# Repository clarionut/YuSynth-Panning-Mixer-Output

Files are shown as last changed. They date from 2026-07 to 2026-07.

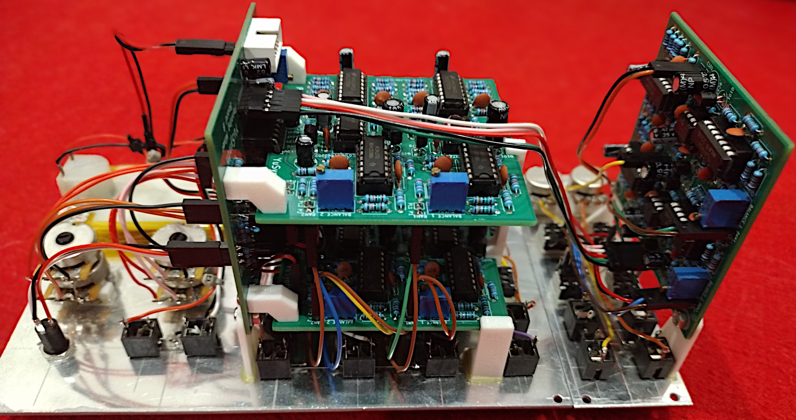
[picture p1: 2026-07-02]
Pictures/PanMixOut1.jpg

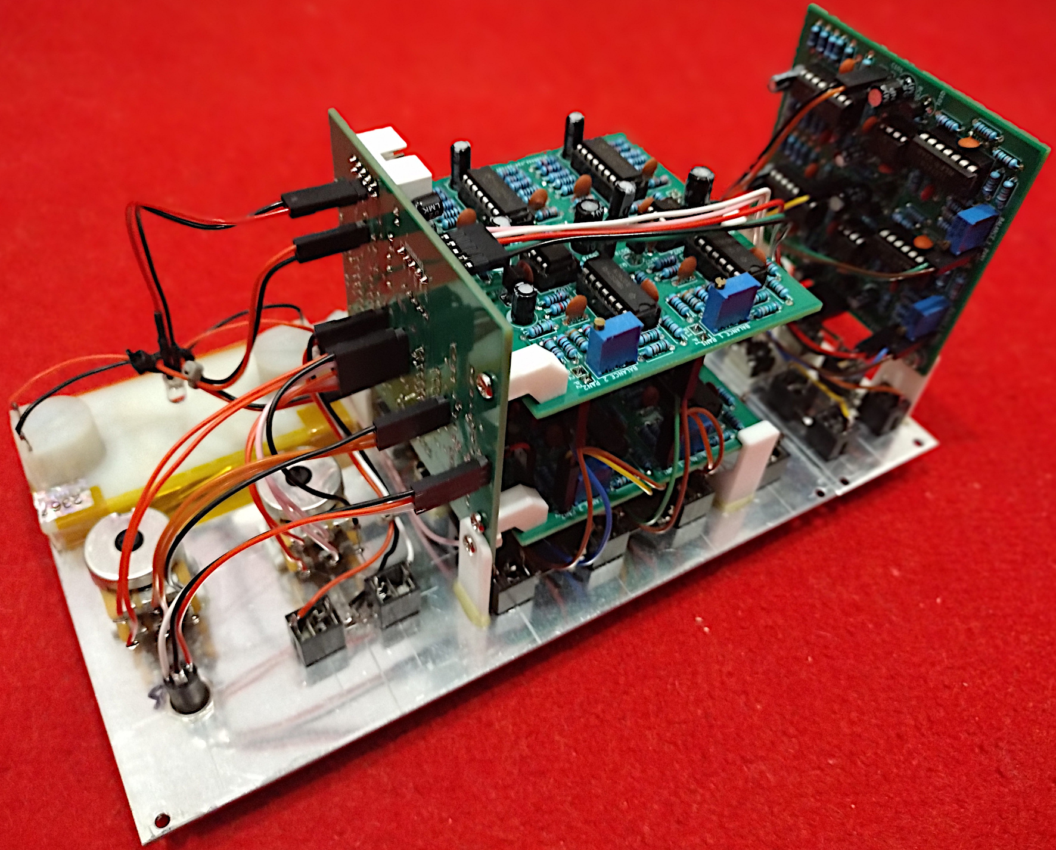
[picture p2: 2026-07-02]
Pictures/PanMixOut2.jpg

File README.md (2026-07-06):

# YuSynth Panning Mixer/Output
An extensible version of the YuSynth Output mixer &amp; VC-panner, minus the tone control circuitry.



Very early in the construction of my modular synth it became obvious that I was going to need a multi-channel mixer as an output stage. I'd already built a few YuSynth modules, so his [Mixout-VC Panner](https://yusynth.net/Modular/EN/MIXOUT/index.html) seemed like a promising choice especially as I had an old dual VU meter which could be pressed into service.

The original design includes a passive tone control circuit (which I chose to omit) and uses a two-board architecture with the four VC panner circuits on one board and the mixer and output circuitry on another. My synth is in Eurorack format, so I wanted to keep the board sizes as small as possible (which also makes them cheaper!). I decided to use an alternative physical architecture with the mixer output board (board B in my design) as a motherboard, with two 2-channel VC-panner boards (board A) plugged into it using pin headers.

This allows easy extensibility by adding further 2-channel VC-panner boards mounted on their own panels, daisy-chained from a header on the motherboard. I have indeed added an additional pair of inputs since originally building the module. Details of the construction are shown in the [pictures](https://github.com/clarionut/YuSynth-Panning-Mixer-Output/tree/main/Pictures) folder. Note that the two VC-panner boards mounted on the motherboard have the header pins on the front side on one board and the back side on the other to keep the wiring as clean as possible. Most of the pin headers on the motherboard are on the back side of the board. The pictures also show the additional input board and panel.

I replaced the original non-backlit VU meter with one which can be illuminated, and soldered a 2 pin header to the back of the main power input connection with flying leads to the resistor/LED positioned behind the meter.

The [schematic](https://github.com/clarionut/YuSynth-Panning-Mixer-Output/tree/main/Schematic) folder contains PDFs of the schematic and layout for the VC-panner boards (A) and the motherboard (B). The Kicad projects for these are in their own individual subfolders.

I've also include the [gerbers](https://github.com/clarionut/YuSynth-Panning-Mixer-Output/tree/main/Gerbers) in case these are of direct use to anyone.

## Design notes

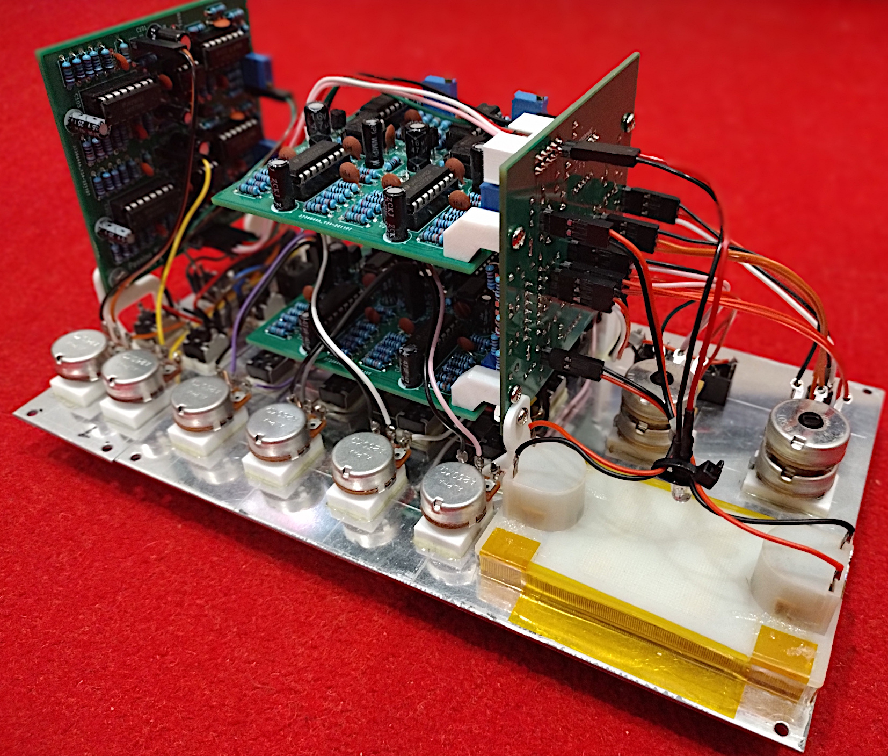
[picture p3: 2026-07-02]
Pictures/PanMixOut3.jpg

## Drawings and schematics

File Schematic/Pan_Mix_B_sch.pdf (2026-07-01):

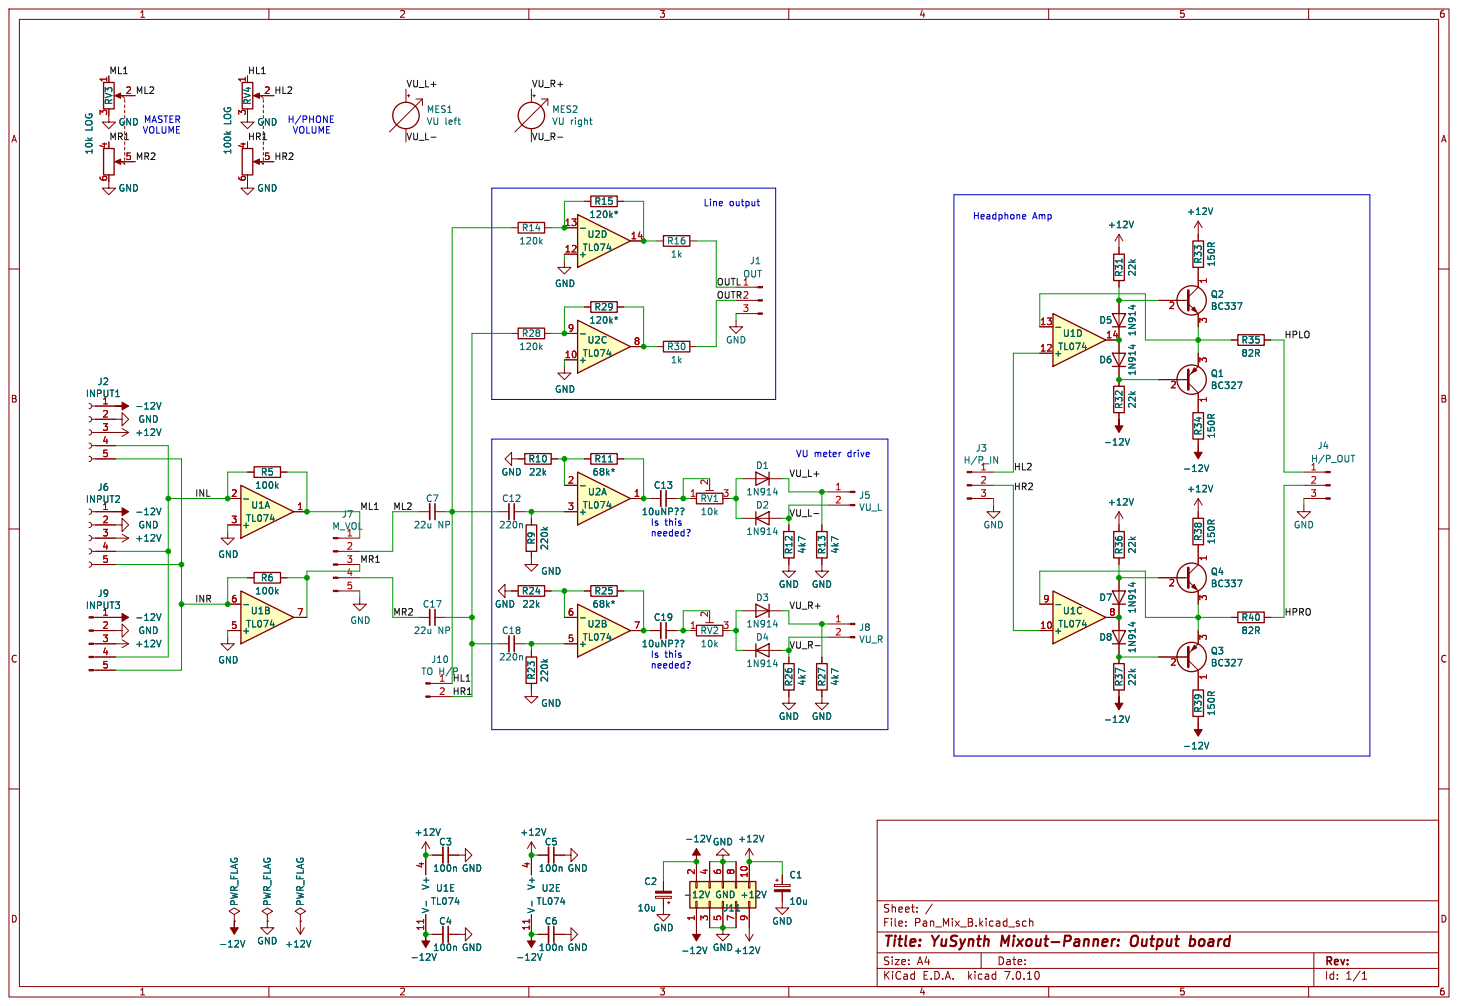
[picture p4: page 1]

10k MES2 VU right MES1 VU left +
1k GND

6 GND GND GND RV3 10k LOG

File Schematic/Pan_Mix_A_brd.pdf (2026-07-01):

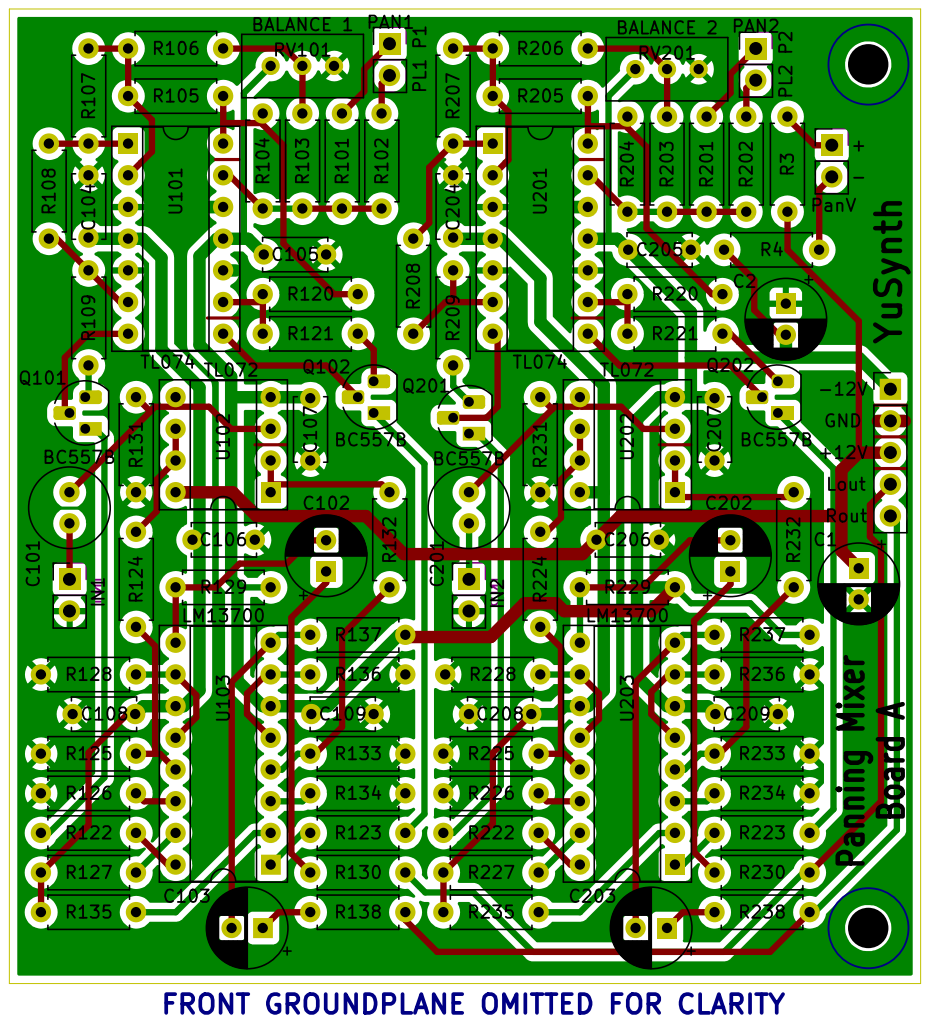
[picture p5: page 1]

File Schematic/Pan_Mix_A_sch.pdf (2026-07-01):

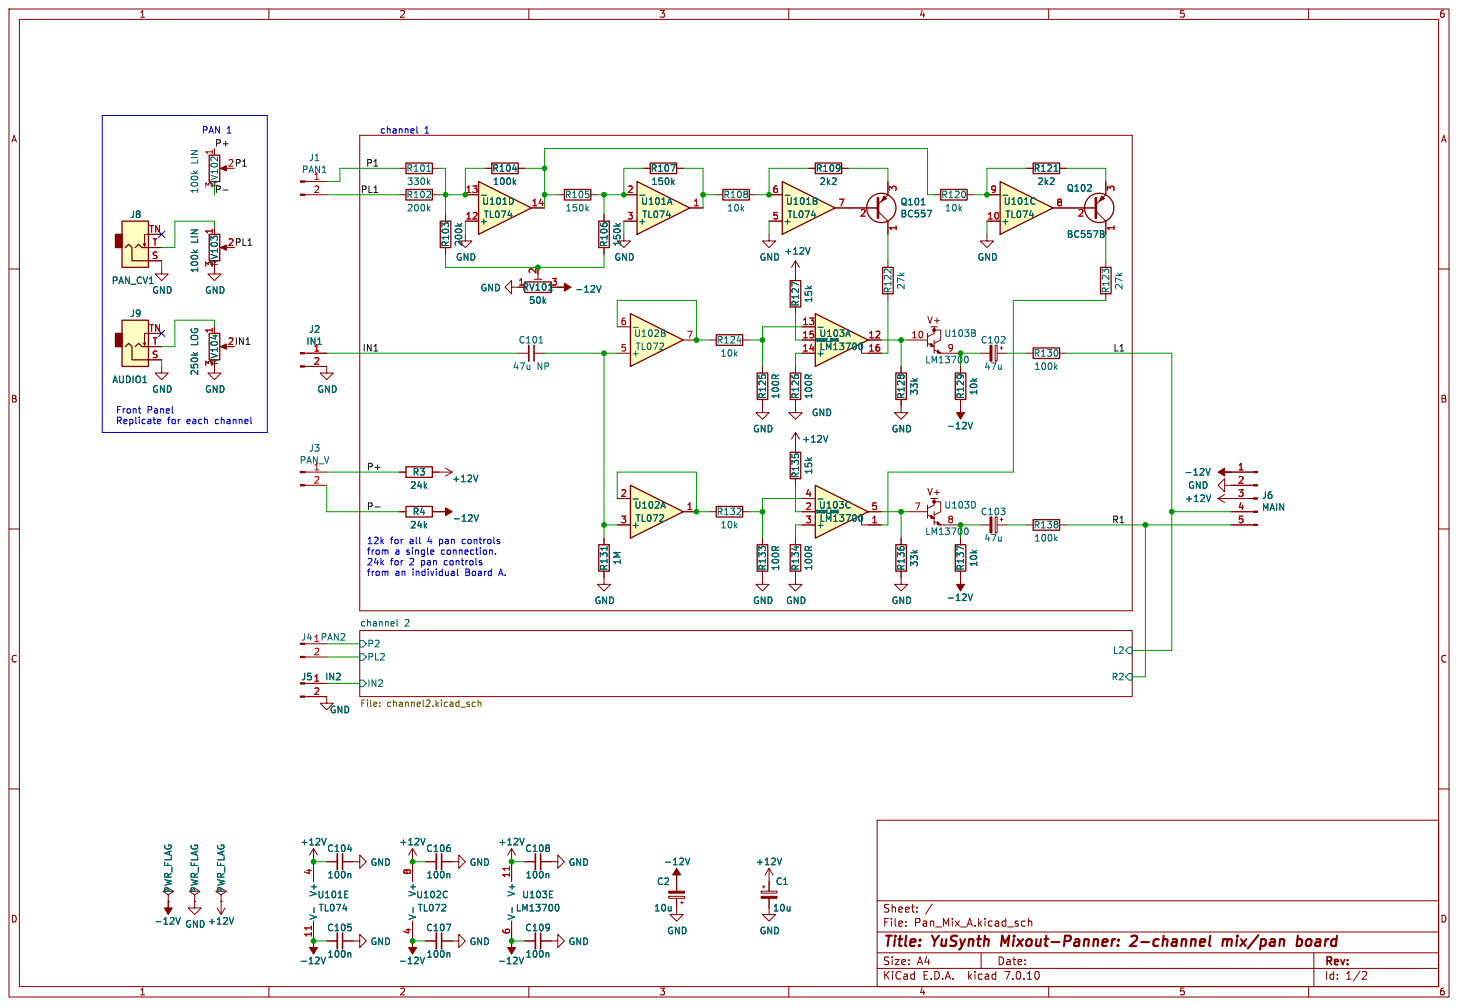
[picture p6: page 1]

12k for all 4 pan controls
from a single connection. 24k for 2 pan controls

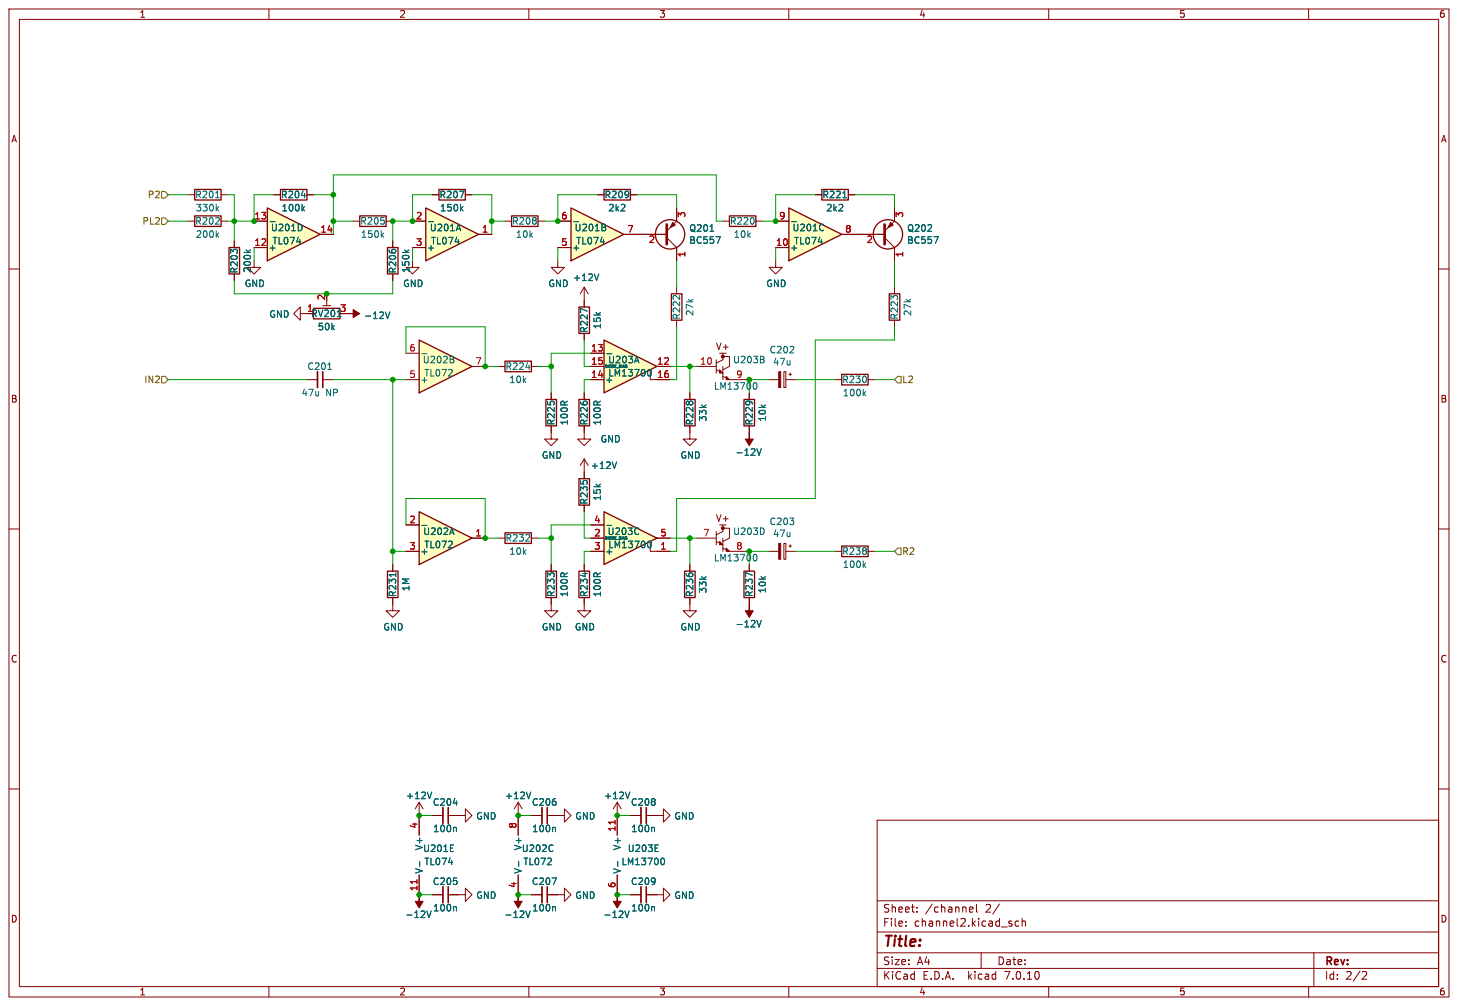
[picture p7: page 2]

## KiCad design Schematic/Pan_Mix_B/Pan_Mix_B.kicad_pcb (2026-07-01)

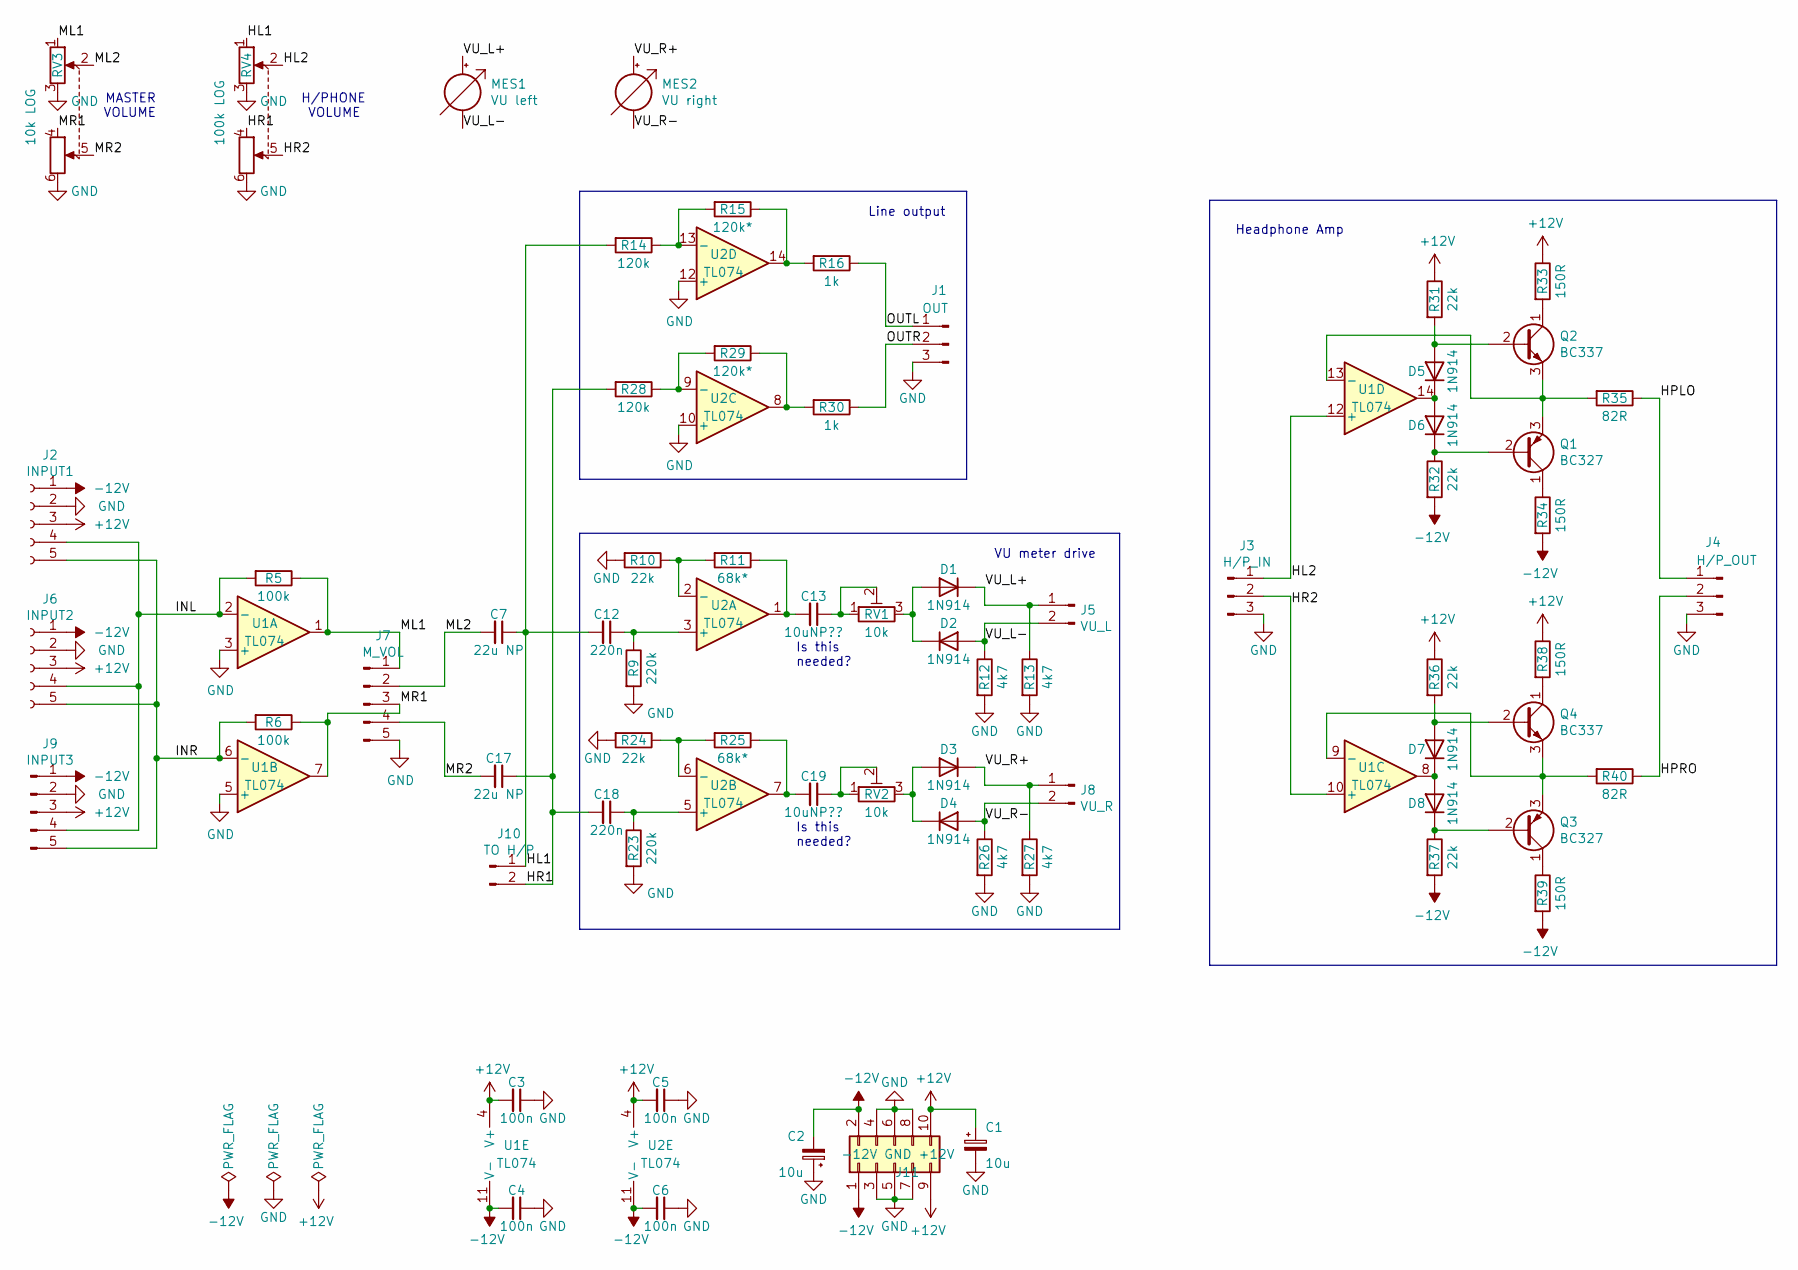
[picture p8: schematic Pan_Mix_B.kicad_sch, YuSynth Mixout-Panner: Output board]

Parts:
C1, C2: 10u; CP_Radial_D6.3mm_P2.50mm
C3, C4, C5, C6: 100n; C_Disc_D6.0mm_W2.5mm_P5.00mm
C7, C17: 22u NP; CP_Radial_D7.5mm_P2.50mm
C12, C18: 220n; C_Rect_L7.0mm_W3.5mm_P5.00mm
C13, C19: 10uNP??; CP_Radial_D6.3mm_P2.50mm
D1, D2, D3, D4, D5, D6, D7, D8: 1N914; D_DO-35_SOD27_P7.62mm_Horizontal
J1: OUT; PinHeader_1x03_P2.54mm_Vertical
J2: INPUT1; PinSocket_1x05_P2.54mm_Vertical
J3: H/P_IN; PinHeader_1x03_P2.54mm_Vertical
J4: H/P_OUT; PinHeader_1x03_P2.54mm_Vertical
J5: VU_L; PinHeader_1x02_P2.54mm_Vertical
J6: INPUT2; PinSocket_1x05_P2.54mm_Vertical
J7: M_VOL; PinHeader_1x05_P2.54mm_Vertical
J8: VU_R; PinHeader_1x02_P2.54mm_Vertical
J9: INPUT3; PinHeader_1x05_P2.54mm_Vertical
J10: TO H/P; PinHeader_1x02_P2.54mm_Vertical
J11: -12V GND +12V; PinHeader_2x05_P2.54mm_Vertical
MES1: VU left; L_Axial_L9.5mm_D4.0mm_P2.54mm_Vertical_Fastron_SMCC
MES2: VU right; L_Axial_L9.5mm_D4.0mm_P2.54mm_Vertical_Fastron_SMCC
Q1, Q3: BC327; TO-92_HandSolder
Q2, Q4: BC337; TO-92_HandSolder
R5, R6: 100k; R_Axial_DIN0207_L6.3mm_D2.5mm_P7.62mm_Horizontal
R9, R23: 220k; R_Axial_DIN0207_L6.3mm_D2.5mm_P7.62mm_Horizontal
R10, R24, R31, R32, R36, R37: 22k; R_Axial_DIN0207_L6.3mm_D2.5mm_P7.62mm_Horizontal
R11, R25: 68k*; R_Axial_DIN0207_L6.3mm_D2.5mm_P7.62mm_Horizontal
R12, R13, R26, R27: 4k7; R_Axial_DIN0207_L6.3mm_D2.5mm_P7.62mm_Horizontal
R14, R28: 120k; R_Axial_DIN0207_L6.3mm_D2.5mm_P7.62mm_Horizontal
R15, R29: 120k*; R_Axial_DIN0207_L6.3mm_D2.5mm_P7.62mm_Horizontal
R16, R30: 1k; R_Axial_DIN0207_L6.3mm_D2.5mm_P7.62mm_Horizontal
R33, R34, R38, R39: 150R; R_Axial_DIN0207_L6.3mm_D2.5mm_P7.62mm_Horizontal
R35, R40: 82R; R_Axial_DIN0207_L6.3mm_D2.5mm_P7.62mm_Horizontal
RV1, RV2: 10k; Potentiometer_Bourns_3296W_Vertical
RV3: 10k LOG; Potentiometer_ACP_CA6-H2,5_Horizontal
RV4: 100k LOG; Potentiometer_ACP_CA6-H2,5_Horizontal
U1, U2: TL074; DIP-14_W7.62mm_Socket

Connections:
+12V: C1.1, C3.2, C5.2, J2.3, J6.3, J9.3, J11.9, J11.10, R31.1, R33.1, R36.1, R38.1, U1.4 (V+), U2.4 (V+)
-12V: C2.2, C4.2, C6.2, J2.1, J6.1, J9.1, J11.1, J11.2, R32.2, R34.2, R37.2, R39.2, U1.11 (V-), U2.11 (V-)
/HL1: C7.1, C12.2, J10.1, R14.2, RV4.1
/HL2: J3.1, RV4.2, U1.12 (+)
/HPLO: J4.1, R35.1
/HPRO: J4.2, R40.1
/HR1: C17.1, C18.2, J10.2, R28.2, RV4.4
/HR2: J3.2, RV4.5, U1.10 (+)
/INL: J2.4, J6.4, J9.4, R5.2, U1.2 (-)
/INR: J2.5, J6.5, J9.5, R6.2, U1.6 (-)
/ML1: J7.1, R5.1, RV3.1, U1.1
/ML2: C7.2, J7.2, RV3.2
/MR1: J7.3, R6.1, RV3.4, U1.7
/MR2: C17.2, J7.4, RV3.5
/OUTL: J1.1, R16.1
/OUTR: J1.2, R30.1
/VU_L+: D1.1 (K), J5.1, MES1.2 (+), R13.1
/VU_L-: D2.2 (A), J5.2, MES1.1 (-), R12.1
/VU_R+: D3.1 (K), J8.1, MES2.2 (+), R27.1
/VU_R-: D4.2 (A), J8.2, MES2.1 (-), R26.1
GND: C1.2, C2.1, C3.1, C4.1, C5.1, C6.1, J1.3, J2.2, J3.3, J4.3, J6.2, J7.5, J9.2, J11.3, J11.4, J11.5, J11.6, J11.7, J11.8, R9.2, R10.2, R12.2, R13.2, R23.2, R24.2, R26.2, R27.2, RV3.3, RV3.6, RV4.3, RV4.6, U1.3 (+), U1.5 (+), U2.10 (+), U2.12 (+)
unnamed: C13.1, RV1.1, RV1.2
unnamed: C13.2, R11.1, U2.1
unnamed: C19.1, RV2.1, RV2.2
unnamed: C19.2, R25.1, U2.7
unnamed: D1.2 (A), D2.1 (K), RV1.3
unnamed: D3.2 (A), D4.1 (K), RV2.3
unnamed: D5.2 (A), Q2.2 (B), R31.2
unnamed: D5.1 (K), D6.2 (A), U1.14
unnamed: D6.1 (K), Q1.2 (B), R32.1
unnamed: D7.2 (A), Q4.2 (B), R36.2
unnamed: D7.1 (K), D8.2 (A), U1.8
unnamed: D8.1 (K), Q3.2 (B), R37.1
unnamed: Q1.1 (C), R34.1
unnamed: Q1.3 (E), Q2.3 (E), R35.2, U1.13 (-)
unnamed: Q2.1 (C), R33.2
unnamed: Q3.1 (C), R39.1
unnamed: Q3.3 (E), Q4.3 (E), R40.2, U1.9 (-)
unnamed: Q4.1 (C), R38.2
unnamed: R15.1, R16.2, U2.14
unnamed: R29.1, R30.2, U2.8
unnamed: C12.1, R9.1, U2.3 (+)
unnamed: R10.1, R11.2, U2.2 (-)
unnamed: C18.1, R23.1, U2.5 (+)
unnamed: R24.1, R25.2, U2.6 (-)
unnamed: R28.1, R29.2, U2.9 (-)
unnamed: R14.1, R15.2, U2.13 (-)

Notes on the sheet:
Is this needed?
Line output
VU meter drive
Headphone Amp
H/PHONE VOLUME
MASTER VOLUME

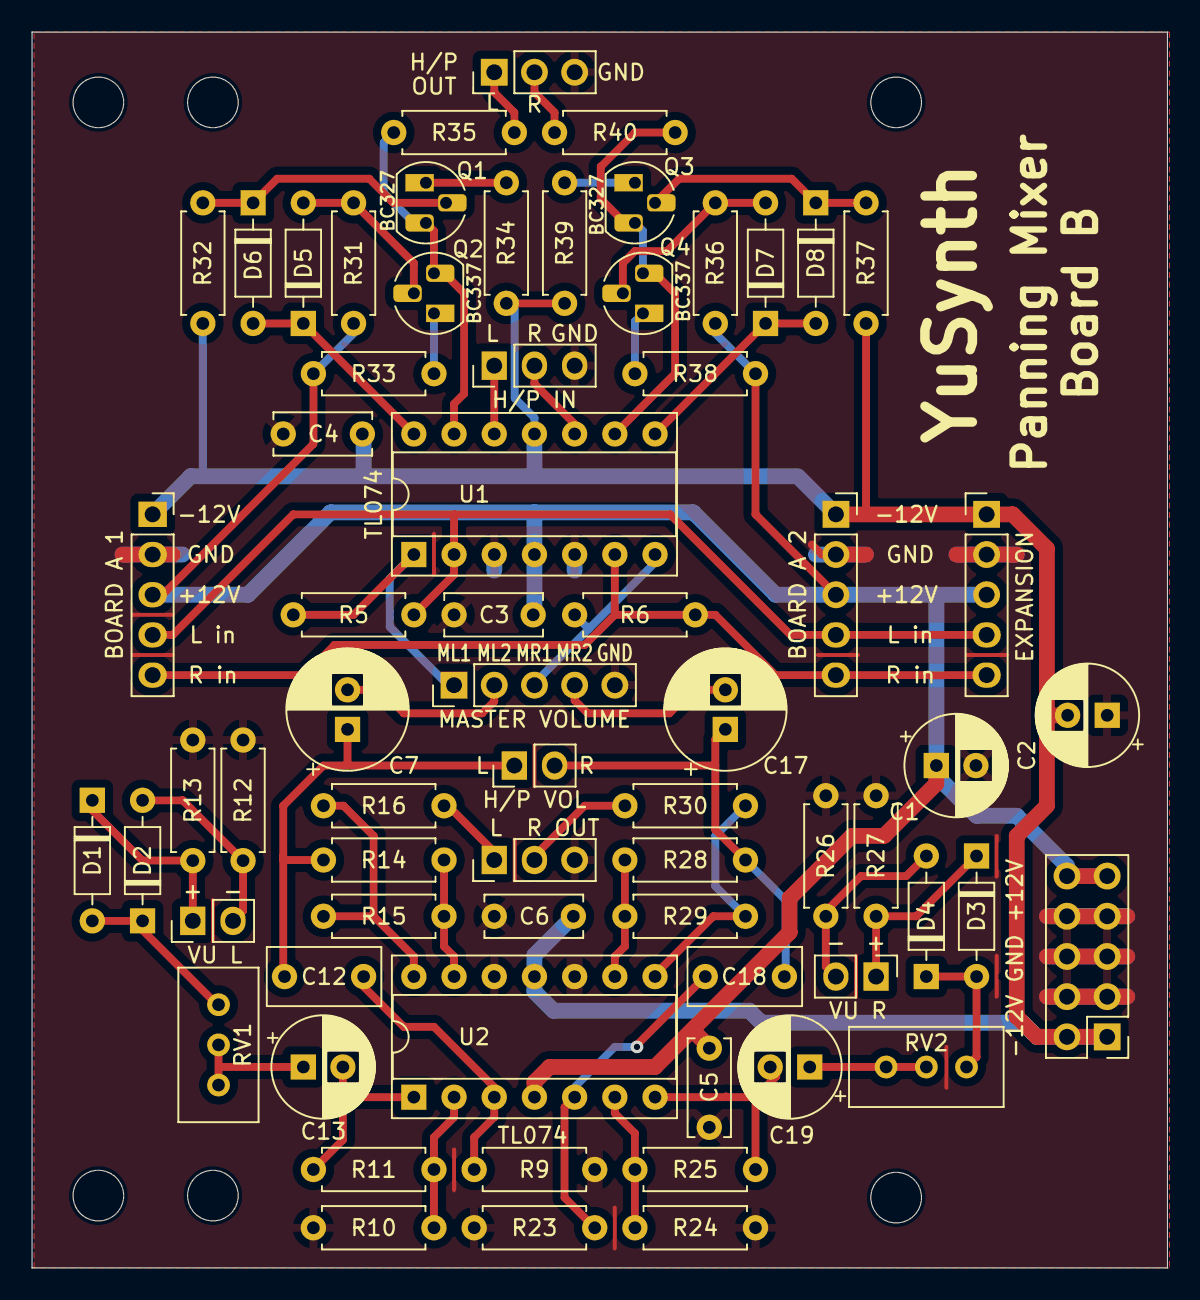
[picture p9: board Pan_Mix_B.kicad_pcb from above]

Board: 2 copper layers, 71.8 x 78.1 mm, 67 parts (0 on the bottom side), 47 nets.

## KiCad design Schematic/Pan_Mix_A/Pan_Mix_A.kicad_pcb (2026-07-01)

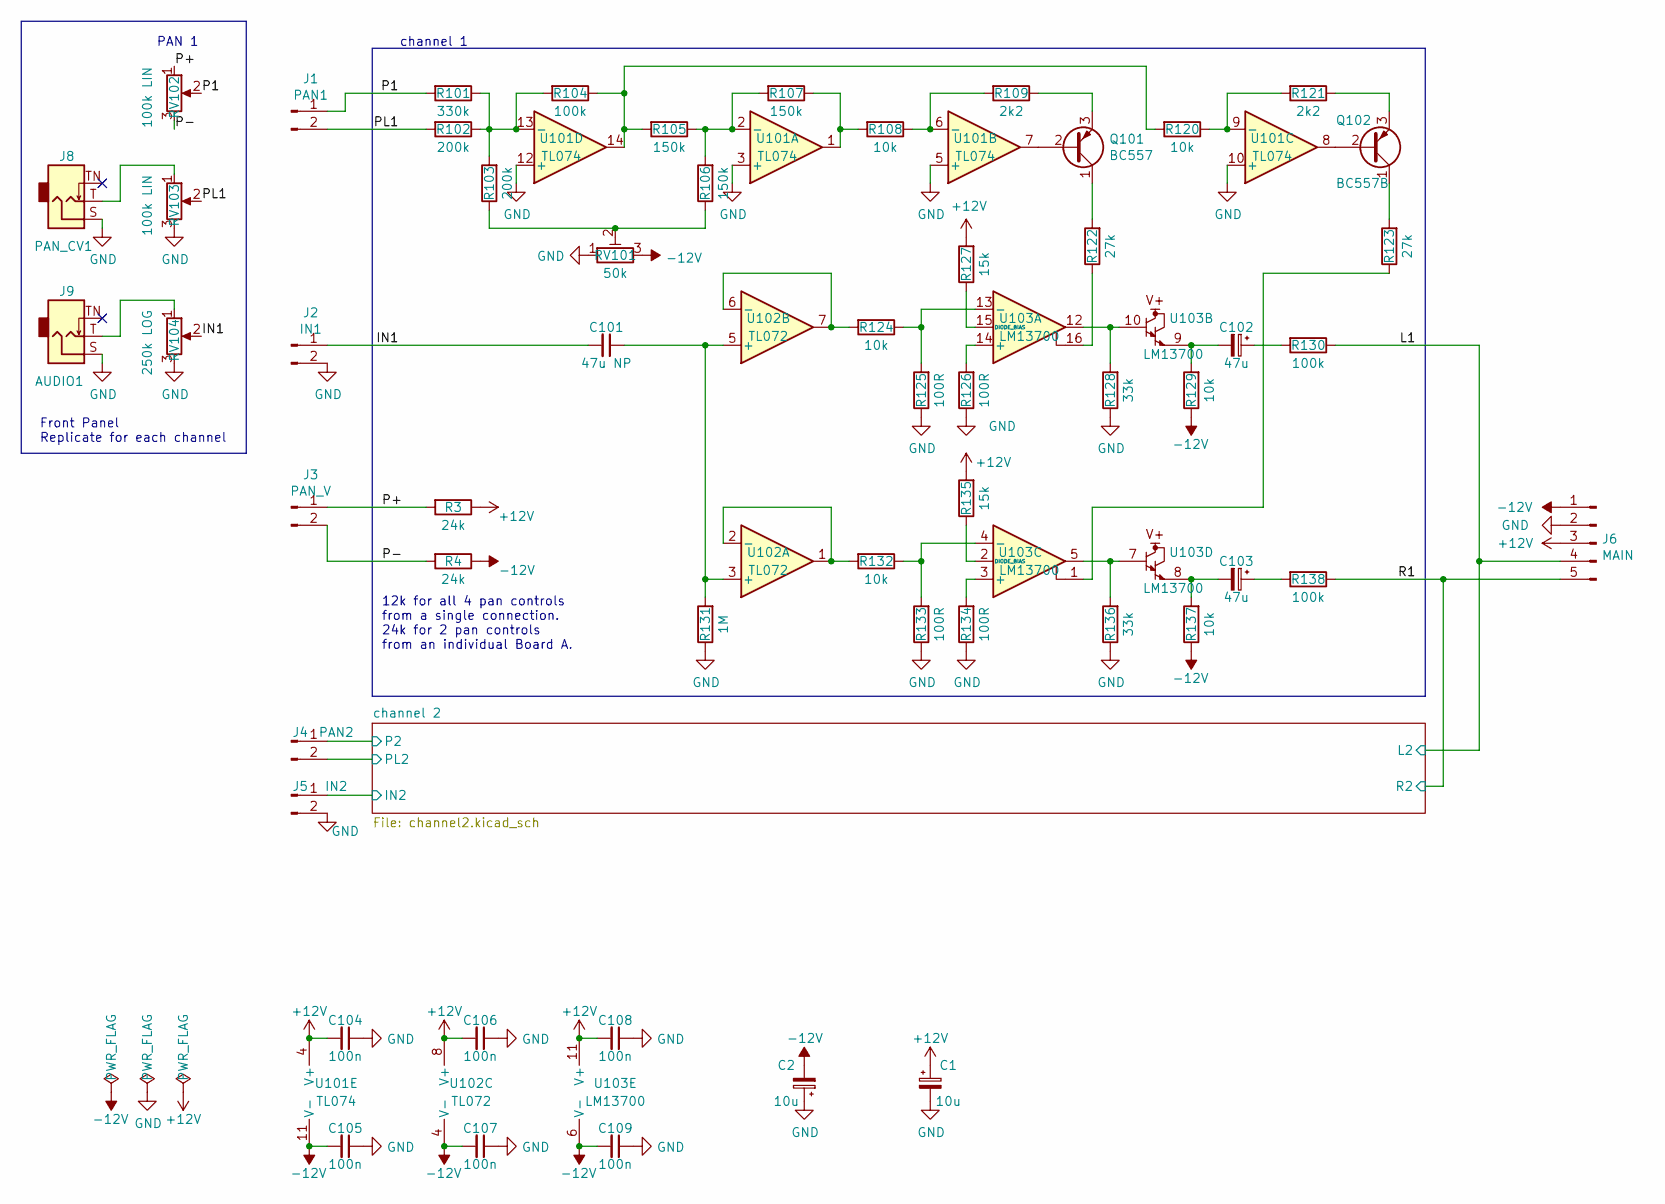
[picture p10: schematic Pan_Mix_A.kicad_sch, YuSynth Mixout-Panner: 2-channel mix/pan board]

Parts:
C1, C2: 10u; CP_Radial_D6.3mm_P2.50mm
C101: 47u NP; C_Radial_D6.3mm_H5.0mm_P2.50mm
C102, C103: 47u; CP_Radial_D6.3mm_P2.50mm
C104, C105, C106, C107, C108, C109: 100n; C_Disc_D5.0mm_W2.5mm_P5.00mm
J1: PAN1; PinHeader_1x02_P2.54mm_Vertical
J2: IN1; PinHeader_1x02_P2.54mm_Vertical
J3: PAN_V; PinHeader_1x02_P2.54mm_Vertical
J4: PAN2; PinHeader_1x02_P2.54mm_Vertical
J5: IN2; PinHeader_1x02_P2.54mm_Vertical
J6: MAIN; PinHeader_1x05_P2.54mm_Vertical
J8: PAN_CV1; Jack_3.5mm_CUI_SJ-3524-SMT_Horizontal
J9: AUDIO1; Jack_3.5mm_CUI_SJ-3524-SMT_Horizontal
Q101: BC557; TO-92_HandSolder
Q102: BC557B; TO-92_HandSolder
R3, R4: 24k; R_Axial_DIN0207_L6.3mm_D2.5mm_P7.62mm_Horizontal
R101: 330k; R_Axial_DIN0207_L6.3mm_D2.5mm_P7.62mm_Horizontal
R102, R103: 200k; R_Axial_DIN0207_L6.3mm_D2.5mm_P7.62mm_Horizontal
R104, R130, R138: 100k; R_Axial_DIN0207_L6.3mm_D2.5mm_P7.62mm_Horizontal
R105, R106, R107: 150k; R_Axial_DIN0207_L6.3mm_D2.5mm_P7.62mm_Horizontal
R108, R120, R124, R129, R132, R137: 10k; R_Axial_DIN0207_L6.3mm_D2.5mm_P7.62mm_Horizontal
R109, R121: 2k2; R_Axial_DIN0207_L6.3mm_D2.5mm_P7.62mm_Horizontal
R122, R123: 27k; R_Axial_DIN0207_L6.3mm_D2.5mm_P7.62mm_Horizontal
R125, R126, R133, R134: 100R; R_Axial_DIN0207_L6.3mm_D2.5mm_P7.62mm_Horizontal
R127, R135: 15k; R_Axial_DIN0207_L6.3mm_D2.5mm_P7.62mm_Horizontal
R128, R136: 33k; R_Axial_DIN0207_L6.3mm_D2.5mm_P7.62mm_Horizontal
R131: 1M; R_Axial_DIN0207_L6.3mm_D2.5mm_P7.62mm_Horizontal
RV101: 50k; Potentiometer_Bourns_3296W_Vertical
RV102, RV103: 100k LIN; Potentiometer_ACP_CA6-H2,5_Horizontal
RV104: 250k LOG; Potentiometer_ACP_CA6-H2,5_Horizontal
U101: TL074; DIP-14_W7.62mm_Socket
U102: TL072; DIP-8_W7.62mm_Socket
U103: LM13700; DIP-16_W7.62mm_Socket

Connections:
+12V: C1.1, C104.2, C106.2, C108.2, J6.3, R3.1, R127.2, R135.2, U101.4 (V+), U102.8 (V+), U103.11 (V+); also elsewhere on the board
-12V: C2.2, C105.2, C107.2, C109.2, J6.1, R4.1, R129.1, R137.1, RV101.3, U101.11 (V-), U102.4 (V-), U103.6 (V-); also elsewhere on the board
/IN1: C101.2, J2.1, RV104.2
/L1: J6.4, R130.1; also elsewhere on the board
/P1: J1.1, R101.2, RV102.2
/P+: J3.1, R3.2, RV102.1
/P-: J3.2, R4.2, RV102.3
/PL1: J1.2, R102.2, RV103.2
/R1: J6.5, R138.1; also elsewhere on the board
/channel 2/IN2: J5.1; also elsewhere on the board
/channel 2/P2: J4.1; also elsewhere on the board
/channel 2/PL2: J4.2; also elsewhere on the board
GND: C1.2, C2.1, C104.1, C105.1, C106.1, C107.1, C108.1, C109.1, J2.2, J5.2, J6.2, J8.S, J9.S, R125.1, R126.1, R128.1, R131.1, R133.1, R134.1, R136.1, RV101.1, RV103.3, RV104.3, U101.3 (+), U101.5 (+), U101.10 (+), U101.12 (+); also elsewhere on the board
unnamed: C101.1, R131.2, U102.3 (+), U102.5 (+)
unnamed: C102.1, R130.2
unnamed: C102.2, R129.2, U103.9
unnamed: C103.1, R138.2
unnamed: C103.2, R137.2, U103.8
unnamed: J8.T, RV103.1
unnamed: J9.T, RV104.1
unnamed: Q101.1 (C), R122.2
unnamed: Q101.2 (B), U101.7
unnamed: Q101.3 (E), R109.1
unnamed: Q102.1 (C), R123.2
unnamed: Q102.2 (B), U101.8
unnamed: Q102.3 (E), R121.1
unnamed: R101.1, R102.1, R103.2, R104.2, U101.13 (-)
unnamed: R103.1, R106.1, RV101.2
unnamed: R104.1, R105.2, R120.2, U101.14
unnamed: R105.1, R106.2, R107.2, U101.2 (-)
unnamed: R107.1, R108.2, U101.1
unnamed: R108.1, R109.2, U101.6 (-)
unnamed: R120.1, R121.2, U101.9 (-)
unnamed: R122.1, U103.16
unnamed: R123.1, U103.1
unnamed: R124.1, R125.2, U103.13 (-)
unnamed: R124.2, U102.6 (-), U102.7
unnamed: R126.2, U103.14 (+)
unnamed: R127.1, U103.15 (DIODE_BIAS)
unnamed: R128.2, U103.10, U103.12
unnamed: R132.1, R133.2, U103.4 (-)
unnamed: R132.2, U102.1, U102.2 (-)
unnamed: R134.2, U103.3 (+)
unnamed: R135.1, U103.2 (DIODE_BIAS)
unnamed: R136.2, U103.5, U103.7

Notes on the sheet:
PAN 1
12k for all 4 pan controls from a single connection. 24k for 2 pan controls from an individual Board A.
Front Panel Replicate for each channel
channel 1

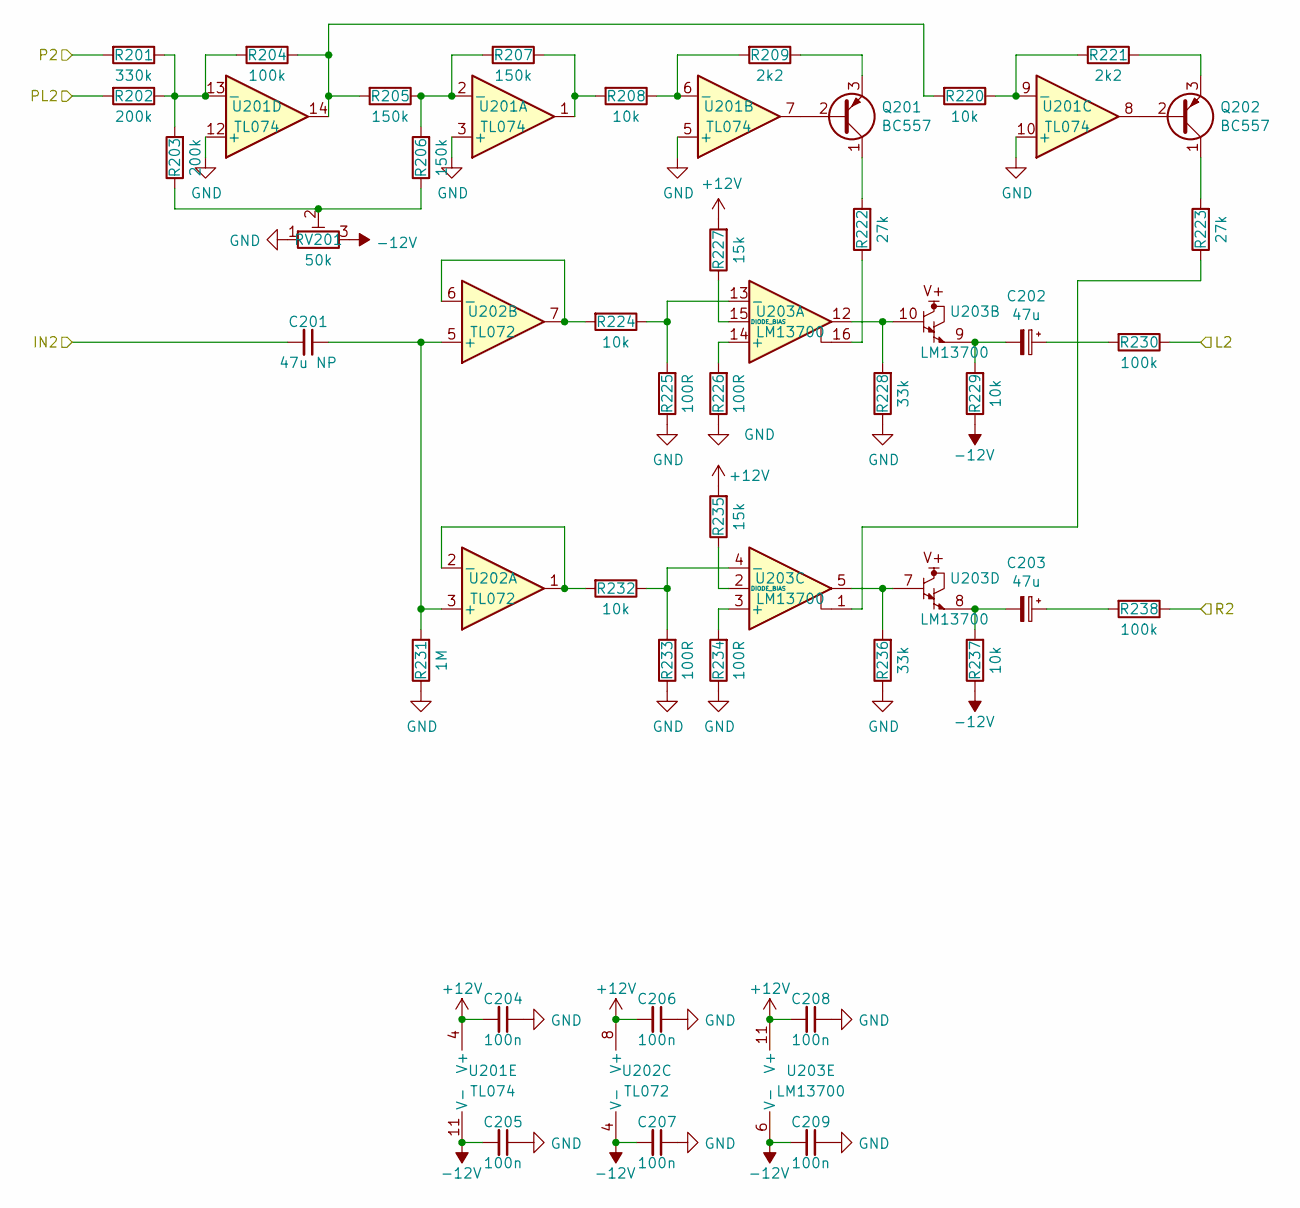
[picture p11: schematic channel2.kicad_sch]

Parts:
C201: 47u NP; C_Radial_D6.3mm_H5.0mm_P2.50mm
C202, C203: 47u; CP_Radial_D6.3mm_P2.50mm
C204, C205, C206, C207, C208, C209: 100n; C_Disc_D5.0mm_W2.5mm_P5.00mm
Q201, Q202: BC557; TO-92_HandSolder
R201: 330k; R_Axial_DIN0207_L6.3mm_D2.5mm_P7.62mm_Horizontal
R202, R203: 200k; R_Axial_DIN0207_L6.3mm_D2.5mm_P7.62mm_Horizontal
R204, R230, R238: 100k; R_Axial_DIN0207_L6.3mm_D2.5mm_P7.62mm_Horizontal
R205, R206, R207: 150k; R_Axial_DIN0207_L6.3mm_D2.5mm_P7.62mm_Horizontal
R208, R220, R224, R229, R232, R237: 10k; R_Axial_DIN0207_L6.3mm_D2.5mm_P7.62mm_Horizontal
R209, R221: 2k2; R_Axial_DIN0207_L6.3mm_D2.5mm_P7.62mm_Horizontal
R222, R223: 27k; R_Axial_DIN0207_L6.3mm_D2.5mm_P7.62mm_Horizontal
R225, R226, R233, R234: 100R; R_Axial_DIN0207_L6.3mm_D2.5mm_P7.62mm_Horizontal
R227, R235: 15k; R_Axial_DIN0207_L6.3mm_D2.5mm_P7.62mm_Horizontal
R228, R236: 33k; R_Axial_DIN0207_L6.3mm_D2.5mm_P7.62mm_Horizontal
R231: 1M; R_Axial_DIN0207_L6.3mm_D2.5mm_P7.62mm_Horizontal
RV201: 50k; Potentiometer_Bourns_3296W_Vertical
U201: TL074; DIP-14_W7.62mm_Socket
U202: TL072; DIP-8_W7.62mm_Socket
U203: LM13700; DIP-16_W7.62mm_Socket

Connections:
+12V: C204.2, C206.2, C208.2, R227.2, R235.2, U201.4 (V+), U202.8 (V+), U203.11 (V+); also elsewhere on the board
-12V: C205.2, C207.2, C209.2, R229.1, R237.1, RV201.3, U201.11 (V-), U202.4 (V-), U203.6 (V-); also elsewhere on the board
/L1: R230.1; also elsewhere on the board
/R1: R238.1; also elsewhere on the board
/channel 2/IN2: C201.2; also elsewhere on the board
/channel 2/P2: R201.2; also elsewhere on the board
/channel 2/PL2: R202.2; also elsewhere on the board
GND: C204.1, C205.1, C206.1, C207.1, C208.1, C209.1, R225.1, R226.1, R228.1, R231.1, R233.1, R234.1, R236.1, RV201.1, U201.3 (+), U201.5 (+), U201.10 (+), U201.12 (+); also elsewhere on the board
unnamed: C201.1, R231.2, U202.3 (+), U202.5 (+)
unnamed: C202.1, R230.2
unnamed: C202.2, R229.2, U203.9
unnamed: C203.1, R238.2
unnamed: C203.2, R237.2, U203.8
unnamed: Q201.1 (C), R222.2
unnamed: Q201.2 (B), U201.7
unnamed: Q201.3 (E), R209.1
unnamed: Q202.1 (C), R223.2
unnamed: Q202.2 (B), U201.8
unnamed: Q202.3 (E), R221.1
unnamed: R201.1, R202.1, R203.2, R204.2, U201.13 (-)
unnamed: R203.1, R206.1, RV201.2
unnamed: R204.1, R205.2, R220.2, U201.14
unnamed: R205.1, R206.2, R207.2, U201.2 (-)
unnamed: R207.1, R208.2, U201.1
unnamed: R208.1, R209.2, U201.6 (-)
unnamed: R220.1, R221.2, U201.9 (-)
unnamed: R222.1, U203.16
unnamed: R223.1, U203.1
unnamed: R224.1, R225.2, U203.13 (-)
unnamed: R224.2, U202.6 (-), U202.7
unnamed: R226.2, U203.14 (+)
unnamed: R227.1, U203.15 (DIODE_BIAS)
unnamed: R228.2, U203.10, U203.12
unnamed: R232.1, R233.2, U203.4 (-)
unnamed: R232.2, U202.1, U202.2 (-)
unnamed: R234.2, U203.3 (+)
unnamed: R235.1, U203.2 (DIODE_BIAS)
unnamed: R236.2, U203.5, U203.7

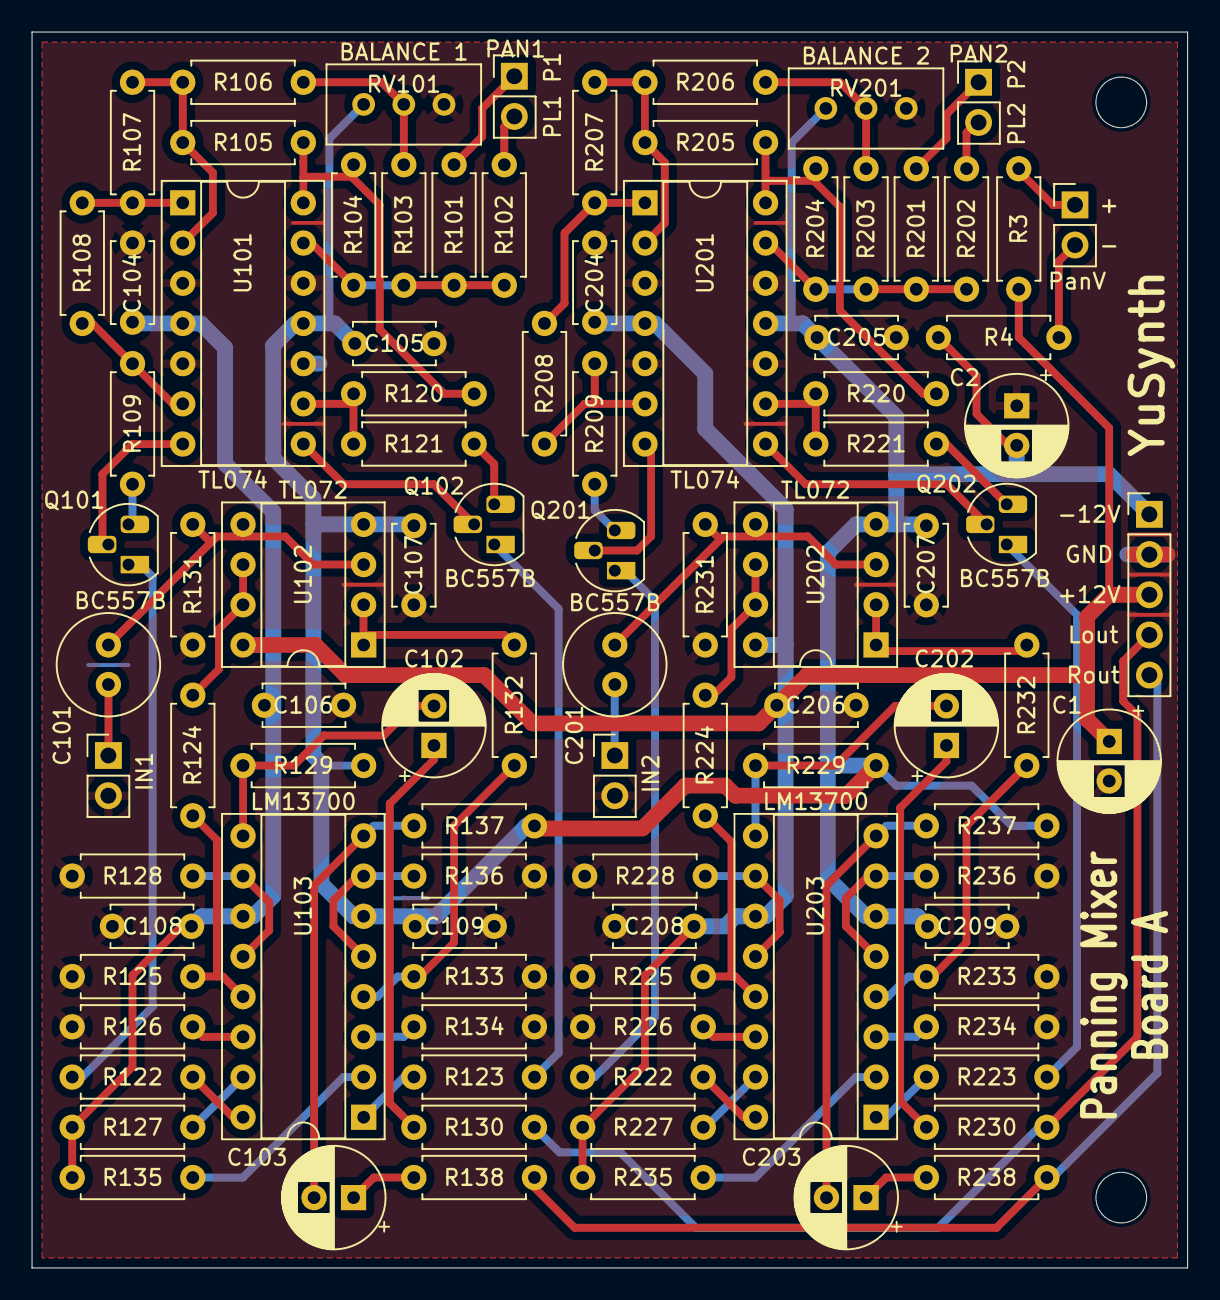
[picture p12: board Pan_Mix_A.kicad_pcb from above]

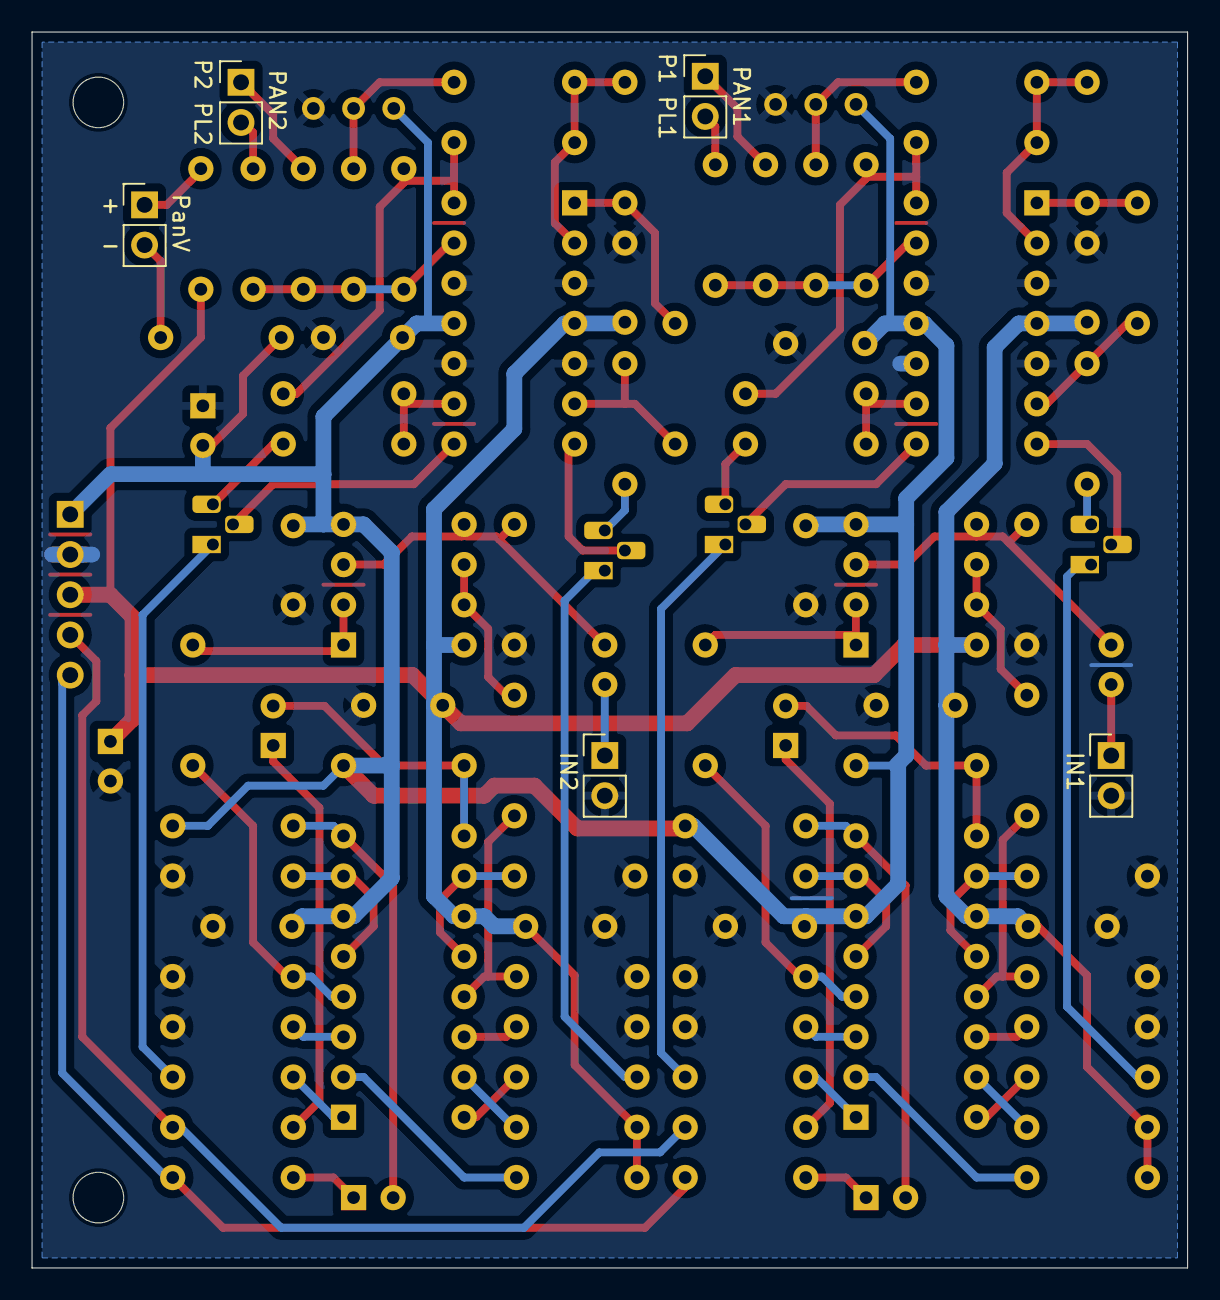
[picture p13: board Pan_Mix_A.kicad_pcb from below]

Board: 2 copper layers, 73.0 x 78.1 mm, 96 parts (5 on the bottom side), 73 nets.
